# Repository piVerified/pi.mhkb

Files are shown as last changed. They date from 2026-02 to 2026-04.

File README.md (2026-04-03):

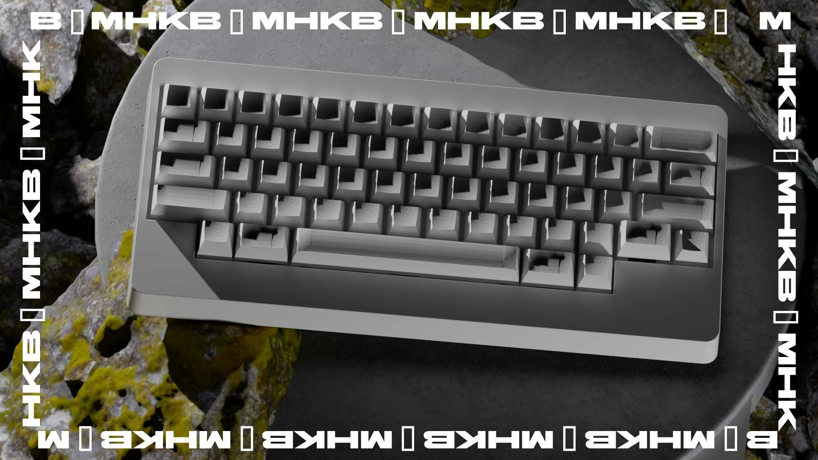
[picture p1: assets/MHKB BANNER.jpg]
BANNER


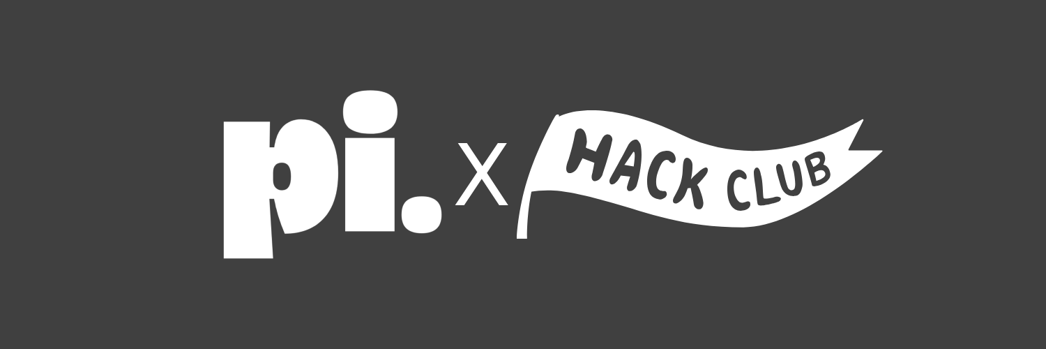
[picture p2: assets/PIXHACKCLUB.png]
COLLAB

# pi.mhkb

Introducing pi.mhkb, a completely custom made HHKB style mechanical keyboard

---
# Features

1. Full HHKB layout with custom key mapping
2. Custom PCB designed in KiCAD
3. 3D printed case designed in Fusion 360

## Fusion 360

### 1. Case

| Top | Side |
| :-: | :--: |
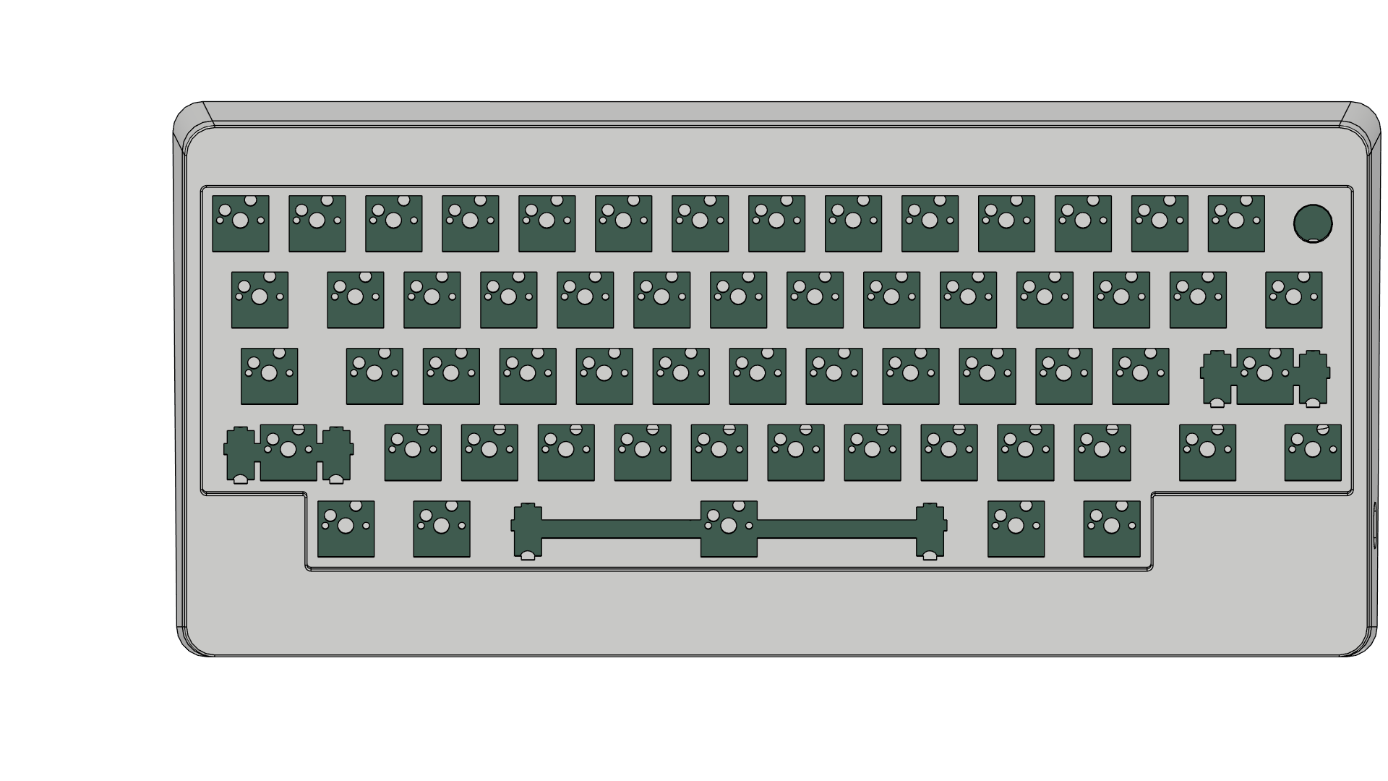
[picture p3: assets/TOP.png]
TOP
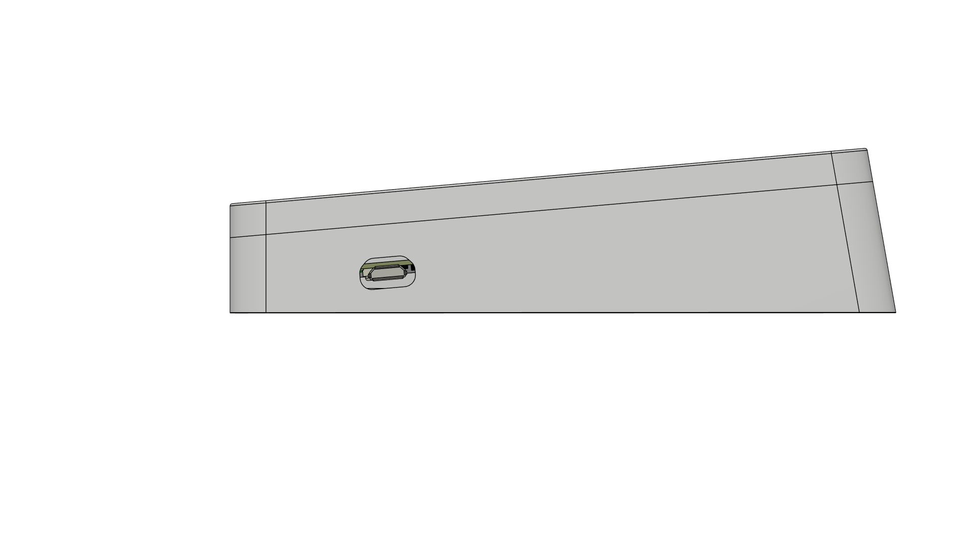
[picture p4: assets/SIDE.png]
SIDE
|  | |

---
## KiCAD

| Schematic |
| :-------: |
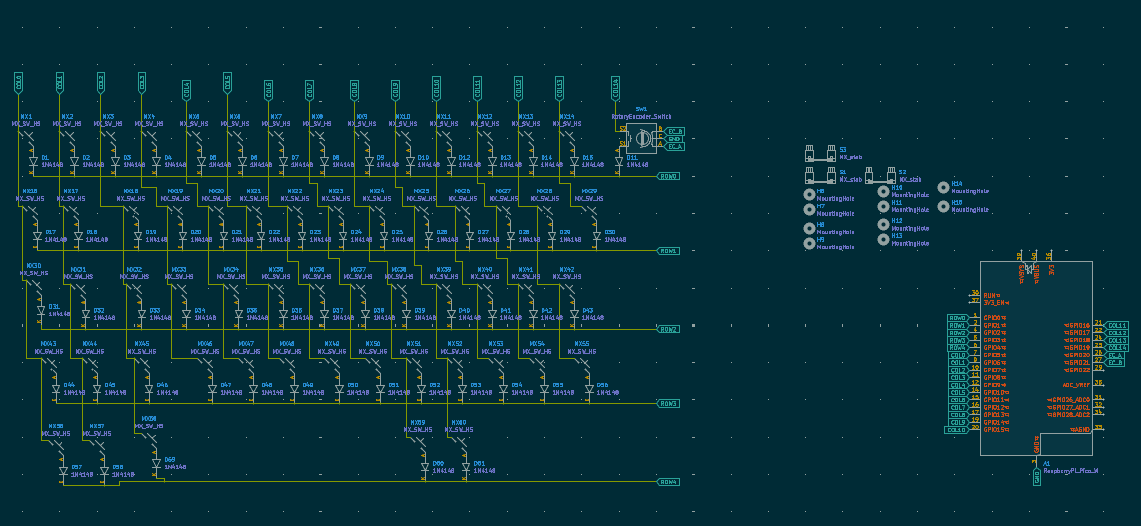
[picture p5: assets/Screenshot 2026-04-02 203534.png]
SCHEMATIC
||
| PCB |
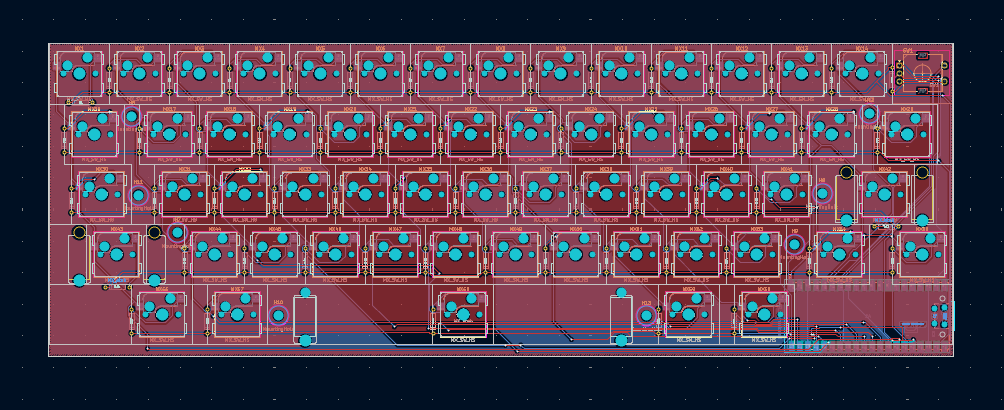
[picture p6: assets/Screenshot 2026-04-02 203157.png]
PCB
|  |

---
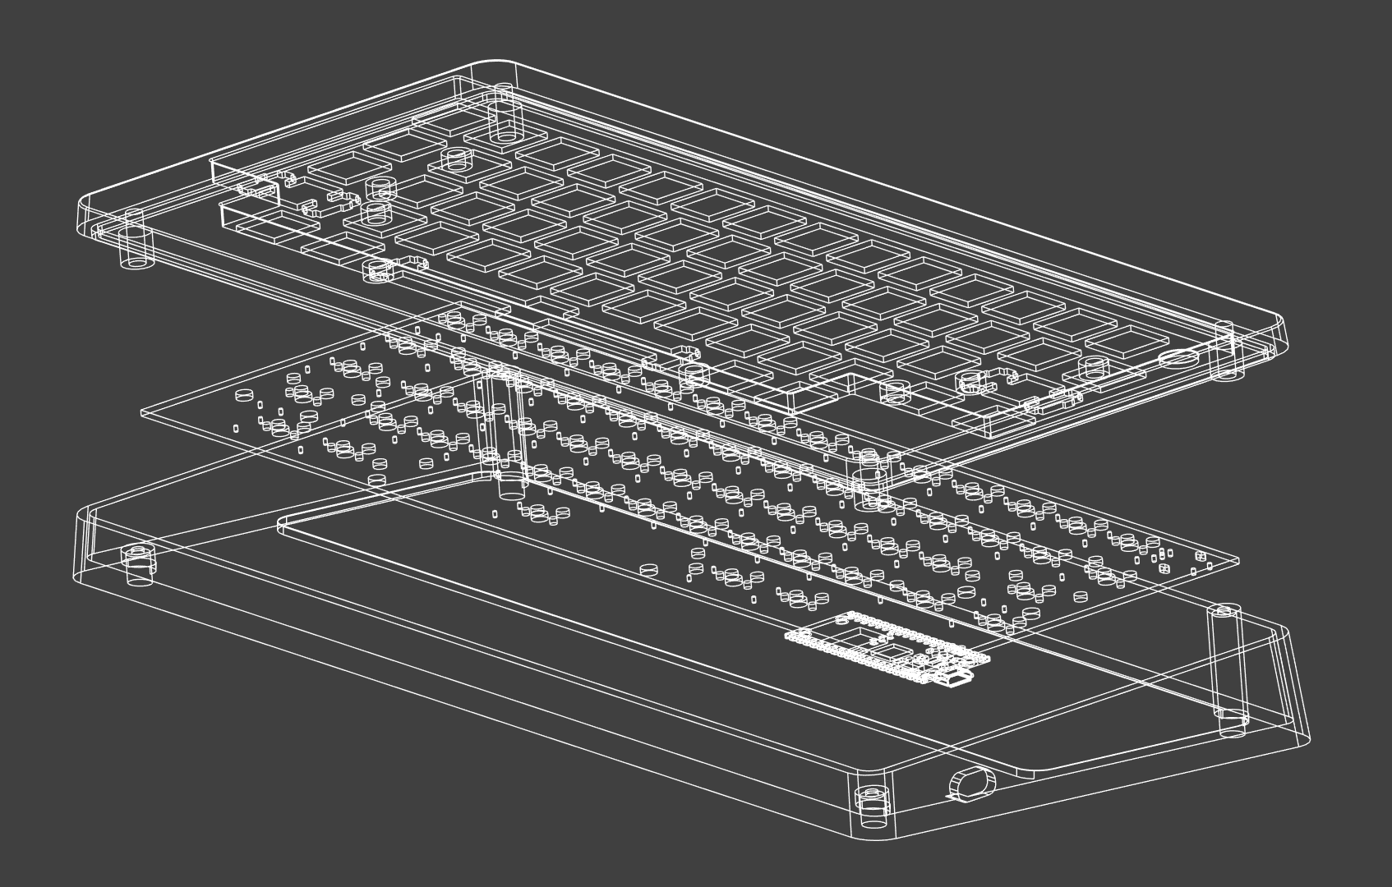
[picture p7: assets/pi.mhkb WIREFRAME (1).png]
WIREFRAME

#BOM
| Name | Purpose | Quantity | Total Cost (USD) | Distributor |
| :--- | :--- | ---: | ---: | :--- |
| PCB | the Brain | 1 | 37.94 | Robu |
| keycaps | covering the keys | 1 | 14.02 | curiosity caps |
| usb cable | for connecting and debugging | 1 | 1.72 | Amazon |
| keyboard Case | Enclousere of the system | 1 | 5.00 | #printinglegion |
| knob | for rotatory knob | 1 | 3.86 | Curiosity Caps |
| Stabilizers (set) | for the biggerkeys stability | 1 | 9.37 | KEEBSMOD |
| Gateron milky yellow | typing | 7 | 14.00 | Meckeys |
| Hotswap Sockets (set of 10) | to make it hotswapable | 7 | 5.81 | Mecheys |
| M3x4 mm Brass Heat Set Threaded Round Insert Nut (x25) | for housing screws | 1 | 0.98 | Robu |
| Raspberry Pi Pico WH | the main controller | 1 | 5.50 | Robu |
| 1N4148 1W Zener Diode | to prevent ghosting of keys | 70 | 0.70 | Robu |

---
# Softwares Used

* KiCAD -> PCB Design
* Fusion 360 -> Case design
* Blender -> Cover Image

---
# Bibliography

> This project would not have been possible without the help of the amazing people of the internet and the Hack Club community.

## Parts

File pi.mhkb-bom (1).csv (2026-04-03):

Name | Purpose | Quantity | Total Cost (USD) | Link | Distributor
screws | to assemble case and | 20 | 1.41 | https://onlyscrews.in/products/chhd-m3-x-6mm-pack-of-22?variant=48458858889529 | onlyscrews
PCB | the Brain | 1 | 37.94 | https://robu.in/cart/ | Robu
keycaps | covering the keys | 1 | 14.02 | https://curiositycaps.in/products/mecha-white-cherry-doubleshot-pbt-keycaps-bag-packaging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 | curiosity caps
usb cable | for connecting and debugging | 1 | 1.72 | https://www.amazon.in/Portronics-Konnect-POR-1079-Charging-Micro/dp/B08CDKQ8T6 | Amazon
keyboard Case | Enclousere of the system | 1 | 5.00 | https://hackclub.enterprise.slack.com/archives/C095YP8GLKT | #printinglegion
knob | for rotatory knob | 1 | 3.86 | https://curiositycaps.in/products/untitled-20oct_19-06?variant=49832025162009 | Curiosity Caps
Stabilizers (set) | for the biggerkeys stability | 1 | 9.37 | https://www.keebsmod.com/products/ws-stupid-stabilizer?variant=48977849745706 | KEEBSMOD
Gateron milky yellow | typing | 7 | 14.00 | https://meckeys.com/shop/accessories/keyboard-accessories/key-switches/gateron-mechanical-pro-switch-5pin/ | Meckeys
Hotswap Sockets (set of 10) | to make it hotswapable | 7 | 5.81 | https://meckeys.com/shop/accessories/keyboard-accessories/key-switches/kailh-hot-swap-socket/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 | Mecheys
M3x4 mm Brass Heat Set Threaded Round Insert Nut (x25) | for housing screws | 1 | 0.98 | https://robu.in/product/m3-x-4-mm-brass-heat-set-knurl-threaded-round-insert-nut-25-pcs/ | Robu
Raspberry Pi Pico WH | the main controller | 1 | 5.50 | https://robu.in/product/raspberry-pi-pico-with-headers/ | Robu
1N4148 1W Zener Diode | to prevent ghosting of keys | 70 | 0.70 | https://robu.in/product/1n4148-1w-zener-diode-pack-of-50/ | Robu

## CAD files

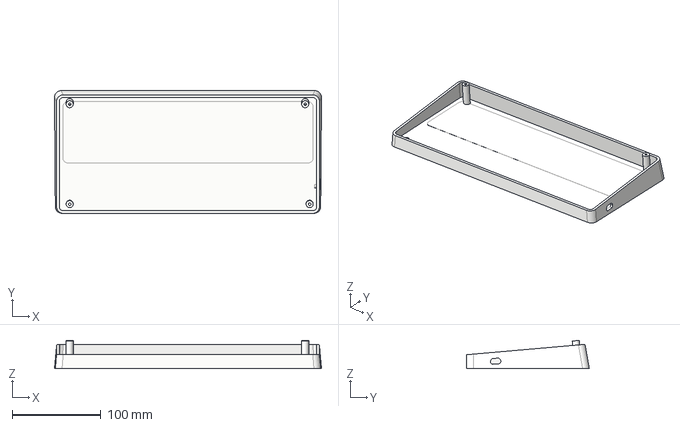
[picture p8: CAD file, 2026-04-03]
CAD/pi.mhkb(base).step
300.4 x 138.0 x 31.7 mm

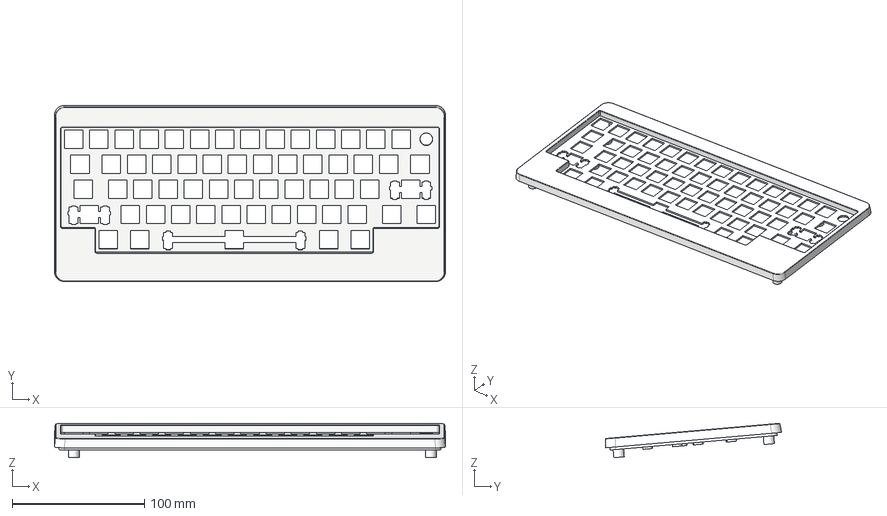
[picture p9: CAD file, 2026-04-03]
CAD/pi.mhkb(top) (2).step
295.8 x 133.2 x 26.0 mm

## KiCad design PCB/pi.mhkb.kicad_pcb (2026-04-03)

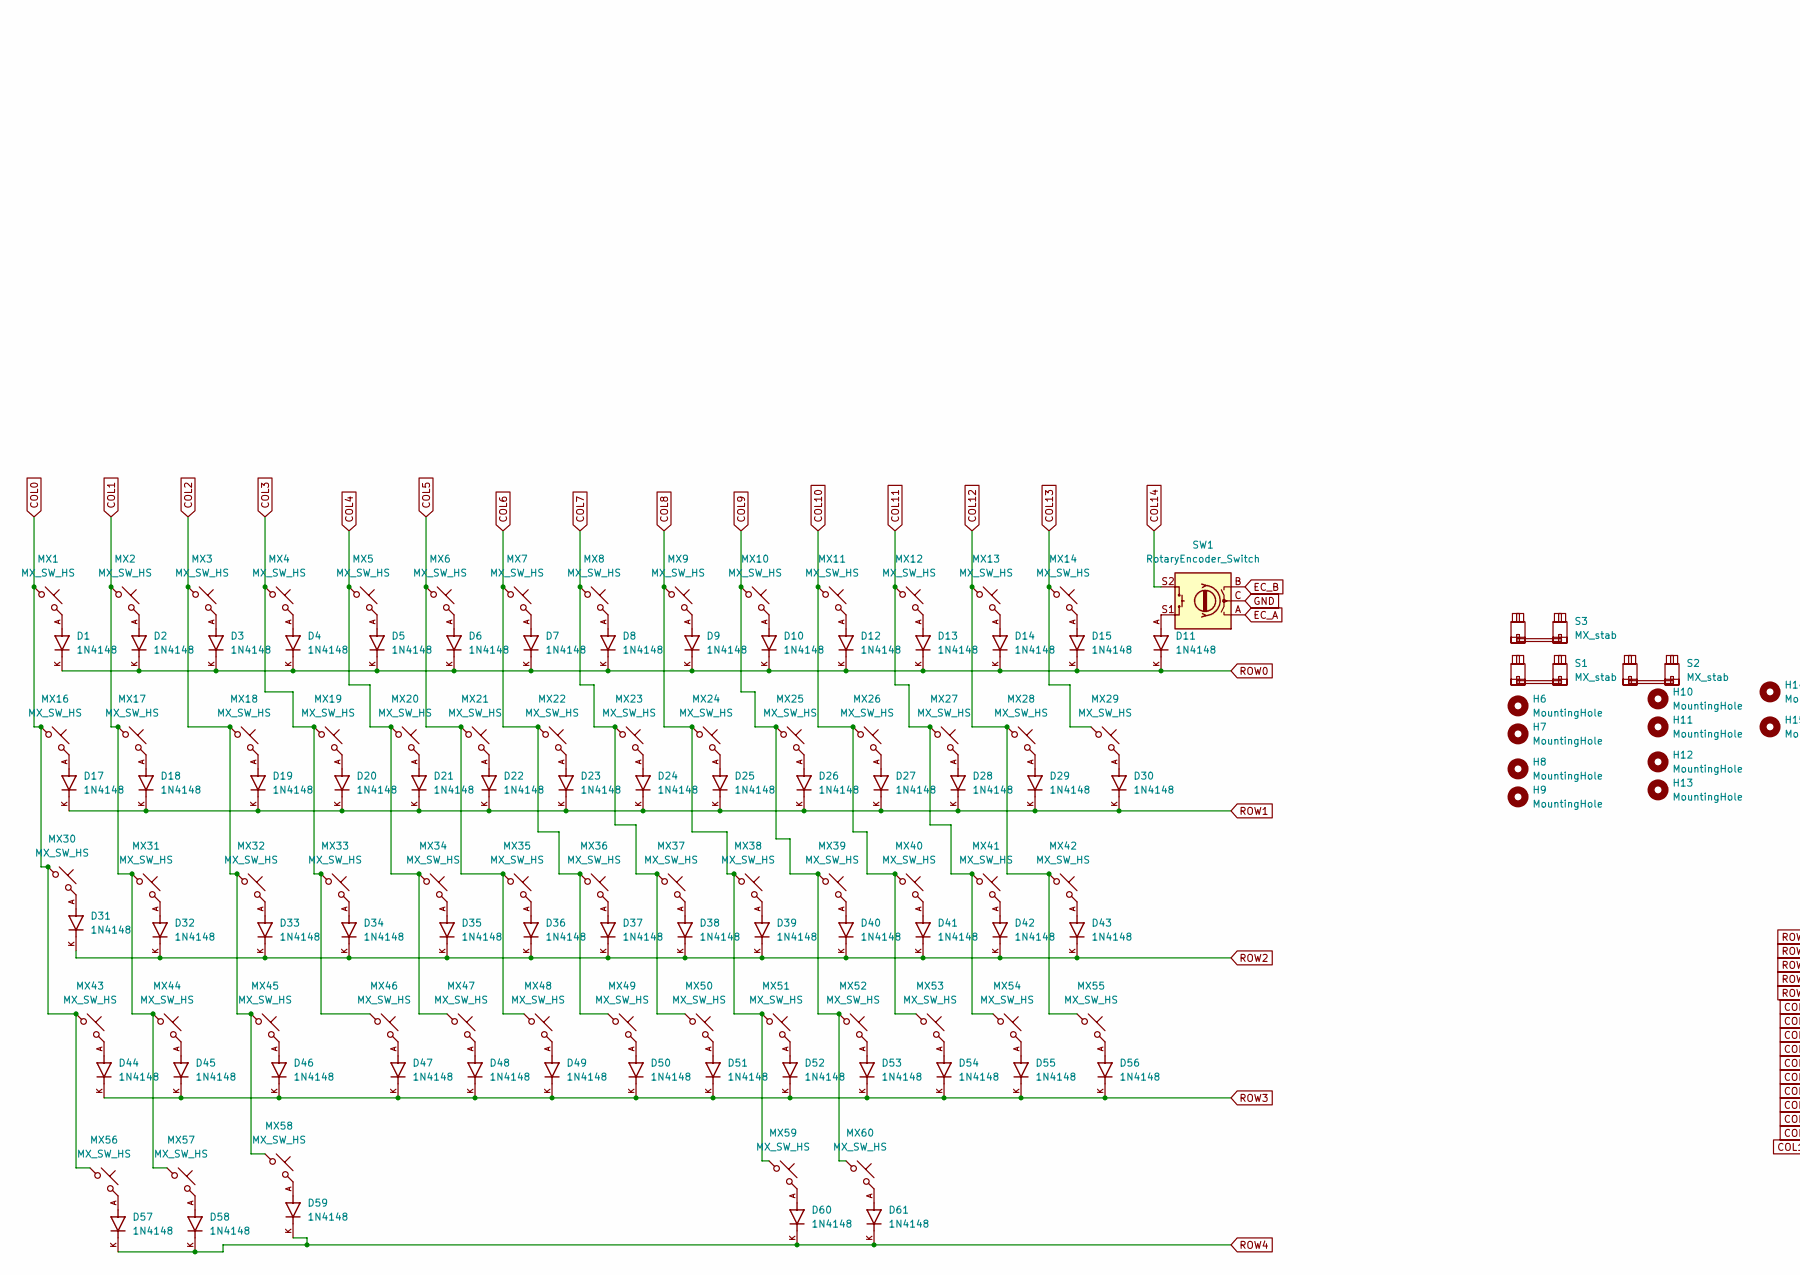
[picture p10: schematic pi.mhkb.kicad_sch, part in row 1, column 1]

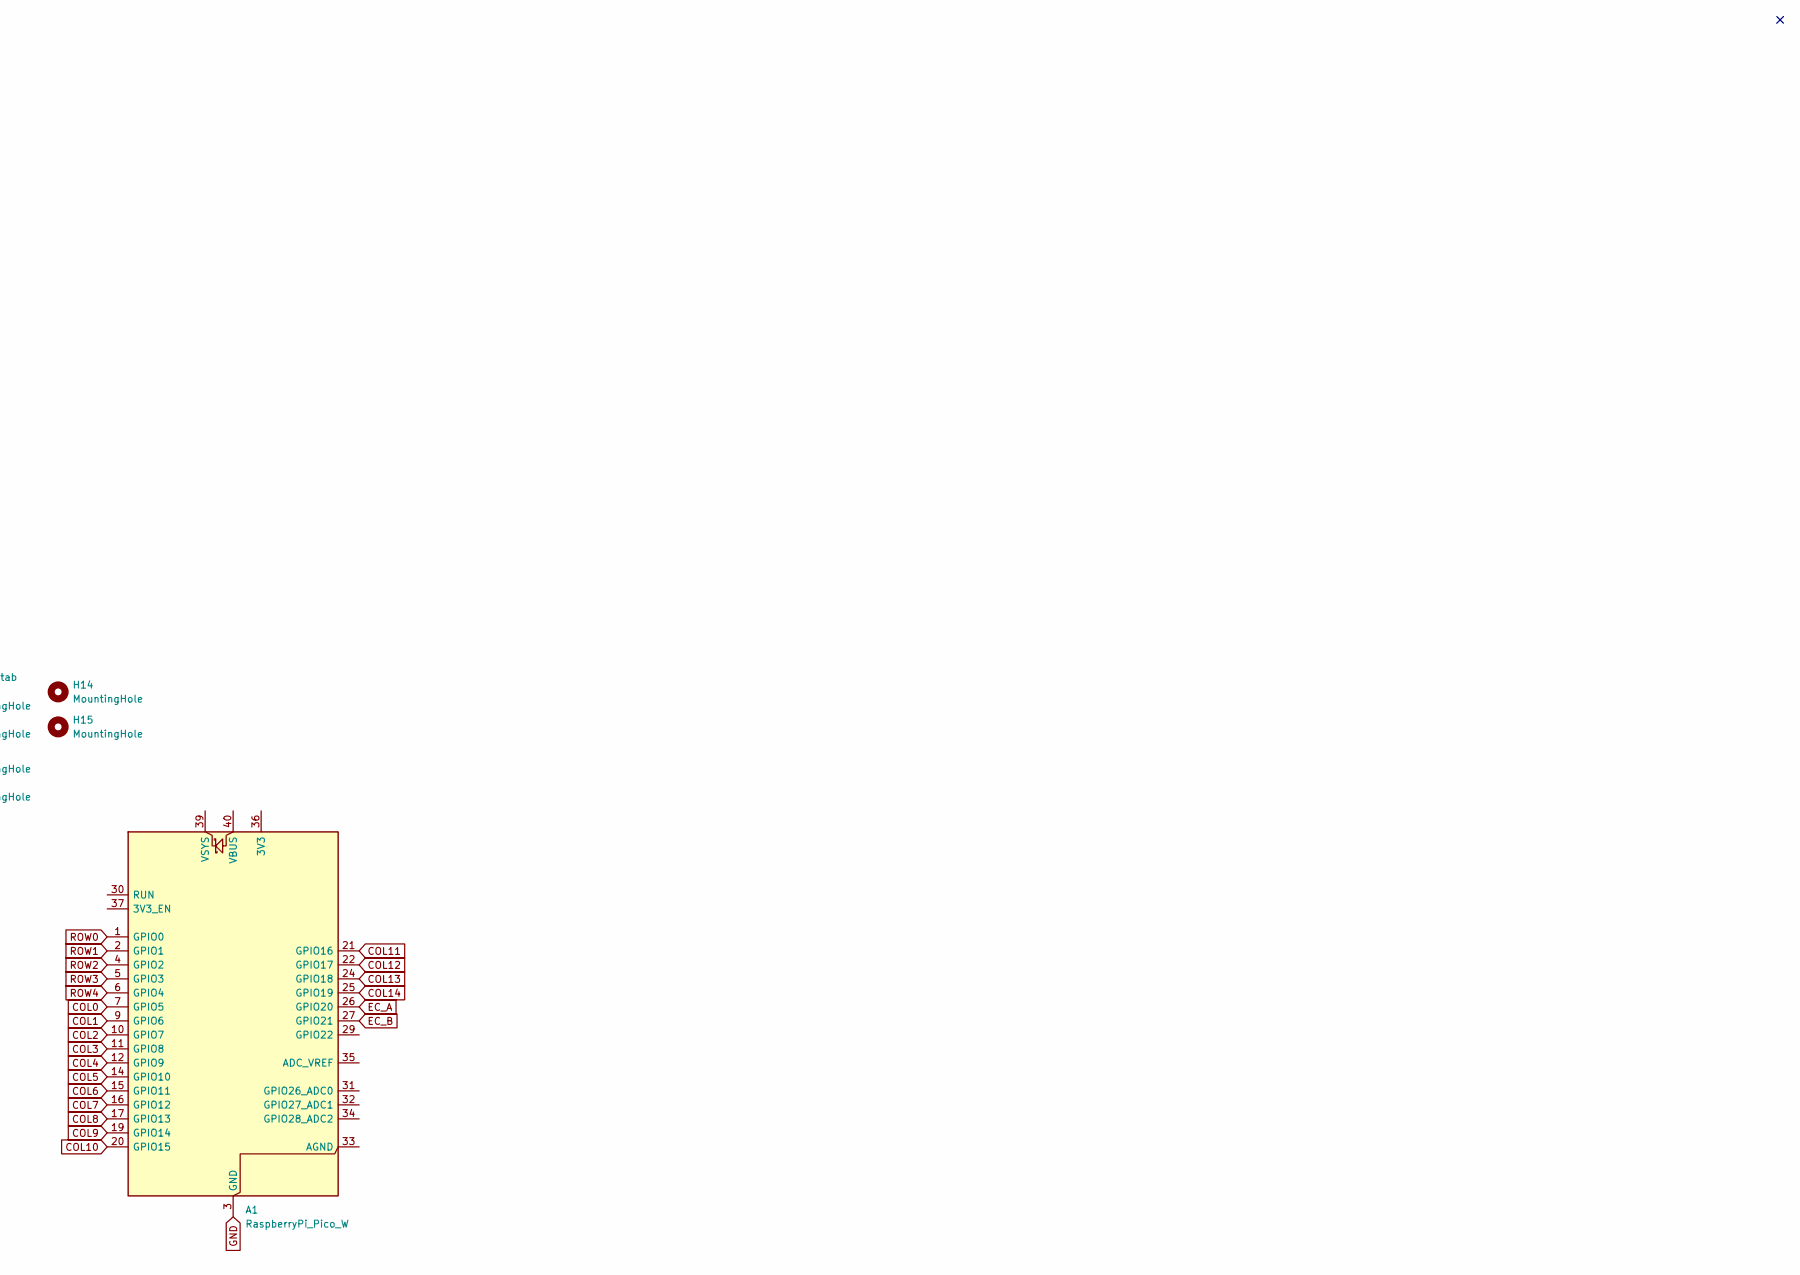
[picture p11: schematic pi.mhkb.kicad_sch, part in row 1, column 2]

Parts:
A1: RaspberryPi_Pico_W; RaspberryPi_Pico_W_SMD_HandSolder
D1, D2, D3, D4, D5, D6, D7, D8, D9, D10, D11, D12, D13, D14, D15, D17, D18, D19, D20, D21, D22, D23, D24, D25, D26, D27, D28, D29, D30, D31, D32, D33, D34, D35, D36, D37, D38, D39, D40, D41, D42, D43, D44, D45, D46, D47, D48, D49, D50, D51, D52, D53, D54, D55, D56, D57, D58, D59, D60, D61: 1N4148; DIODE-1N4148; PARTREV 5
H6, H7, H8, H9, H10, H11, H12, H13, H14, H15: MountingHole; MountingHole_3.2mm_M3
MX1, MX2, MX3, MX4, MX5, MX6, MX7, MX8, MX9, MX10, MX11, MX12, MX13, MX14, MX16, MX17, MX18, MX19, MX20, MX21, MX22, MX23, MX24, MX25, MX26, MX27, MX28, MX29, MX30, MX31, MX32, MX33, MX34, MX35, MX36, MX37, MX38, MX39, MX40, MX41, MX42, MX43, MX44, MX45, MX46, MX47, MX48, MX49, MX50, MX51, MX52, MX53, MX54, MX55, MX56, MX57, MX58, MX59, MX60: MX_SW_HS; SW_Hotswap_Kailh_MX_1.00u
S1, S2: MX_stab; STAB_MX_P_2.25u
S3: MX_stab; Stabilizer_Cherry_MX_6.25u
SW1: RotaryEncoder_Switch; RotaryEncoder_Alps_EC11E-Switch_Vertical_H20mm

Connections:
COL0: A1.7 (GPIO5), MX1.1, MX16.1, MX30.1, MX43.1, MX56.1
COL1: A1.9 (GPIO6), MX2.1, MX17.1, MX31.1, MX44.1, MX57.1
COL2: A1.10 (GPIO7), MX3.1, MX18.1, MX32.1, MX45.1, MX58.1
COL3: A1.11 (GPIO8), MX4.1, MX19.1, MX33.1, MX46.1
COL4: A1.12 (GPIO9), MX5.1, MX20.1, MX34.1, MX47.1
COL5: A1.14 (GPIO10), MX6.1, MX21.1, MX35.1, MX48.1
COL6: A1.15 (GPIO11), MX7.1, MX22.1, MX36.1, MX49.1
COL7: A1.16 (GPIO12), MX8.1, MX23.1, MX37.1, MX50.1
COL8: A1.17 (GPIO13), MX9.1, MX24.1, MX38.1, MX51.1, MX59.1
COL9: A1.19 (GPIO14), MX10.1, MX25.1, MX39.1, MX52.1, MX60.1
COL10: A1.20 (GPIO15), MX11.1, MX26.1, MX40.1, MX53.1
COL11: A1.21 (GPIO16), MX12.1, MX27.1, MX41.1, MX54.1
COL12: A1.22 (GPIO17), MX13.1, MX28.1, MX42.1, MX55.1
COL13: A1.24 (GPIO18), MX14.1, MX29.1
COL14: A1.25 (GPIO19), SW1.S2
EC_A: A1.26 (GPIO20), SW1.A
EC_B: A1.27 (GPIO21), SW1.B
GND: A1.3 (GND), A1.8 (GND), A1.13 (GND), A1.18 (GND), A1.23 (GND), A1.28 (GND), A1.38 (GND), SW1.C
unnamed: D1.A, MX1.2
unnamed: D2.A, MX2.2
unnamed: D3.A, MX3.2
unnamed: D4.A, MX4.2
unnamed: D5.A, MX5.2
unnamed: D6.A, MX6.2
unnamed: D7.A, MX7.2
unnamed: D8.A, MX8.2
unnamed: D9.A, MX9.2
unnamed: D10.A, MX10.2
unnamed: D11.A, SW1.S1
unnamed: D12.A, MX11.2
unnamed: D13.A, MX12.2
unnamed: D14.A, MX13.2
unnamed: D15.A, MX14.2
unnamed: D17.A, MX16.2
unnamed: D18.A, MX17.2
unnamed: D19.A, MX18.2
unnamed: D20.A, MX19.2
unnamed: D21.A, MX20.2
unnamed: D22.A, MX21.2
unnamed: D23.A, MX22.2
unnamed: D24.A, MX23.2
unnamed: D25.A, MX24.2
unnamed: D26.A, MX25.2
unnamed: D27.A, MX26.2
unnamed: D28.A, MX27.2
unnamed: D29.A, MX28.2
unnamed: D30.A, MX29.2
unnamed: D31.A, MX30.2
unnamed: D32.A, MX31.2
unnamed: D33.A, MX32.2
unnamed: D34.A, MX33.2
unnamed: D35.A, MX34.2
unnamed: D36.A, MX35.2
unnamed: D37.A, MX36.2
unnamed: D38.A, MX37.2
unnamed: D39.A, MX38.2
unnamed: D40.A, MX39.2
unnamed: D41.A, MX40.2
unnamed: D42.A, MX41.2
unnamed: D43.A, MX42.2
unnamed: D44.A, MX43.2
unnamed: D45.A, MX44.2
unnamed: D46.A, MX45.2
unnamed: D47.A, MX46.2
unnamed: D48.A, MX47.2
unnamed: D49.A, MX48.2
unnamed: D50.A, MX49.2
unnamed: D51.A, MX50.2
unnamed: D52.A, MX51.2
unnamed: D53.A, MX52.2
unnamed: D54.A, MX53.2
unnamed: D55.A, MX54.2
unnamed: D56.A, MX55.2
unnamed: D57.A, MX56.2
unnamed: D58.A, MX57.2
unnamed: D59.A, MX58.2
unnamed: D60.A, MX59.2
unnamed: D61.A, MX60.2
ROW0: A1.1 (GPIO0), D1.K, D2.K, D3.K, D4.K, D5.K, D6.K, D7.K, D8.K, D9.K, D10.K, D11.K, D12.K, D13.K, D14.K, D15.K
ROW1: A1.2 (GPIO1), D17.K, D18.K, D19.K, D20.K, D21.K, D22.K, D23.K, D24.K, D25.K, D26.K, D27.K, D28.K, D29.K, D30.K
ROW2: A1.4 (GPIO2), D31.K, D32.K, D33.K, D34.K, D35.K, D36.K, D37.K, D38.K, D39.K, D40.K, D41.K, D42.K, D43.K
ROW3: A1.5 (GPIO3), D44.K, D45.K, D46.K, D47.K, D48.K, D49.K, D50.K, D51.K, D52.K, D53.K, D54.K, D55.K, D56.K
ROW4: A1.6 (GPIO4), D57.K, D58.K, D59.K, D60.K, D61.K

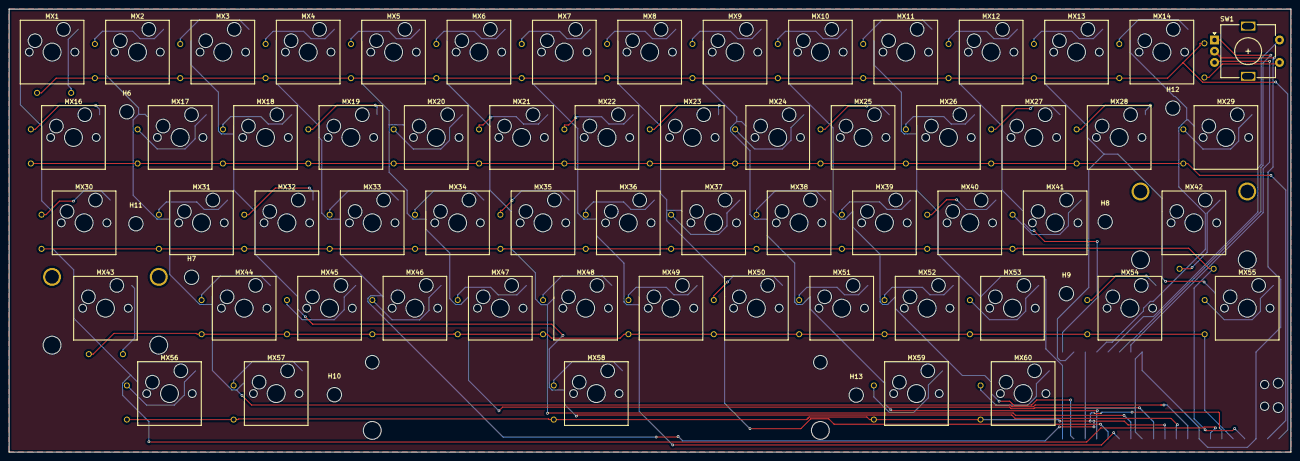
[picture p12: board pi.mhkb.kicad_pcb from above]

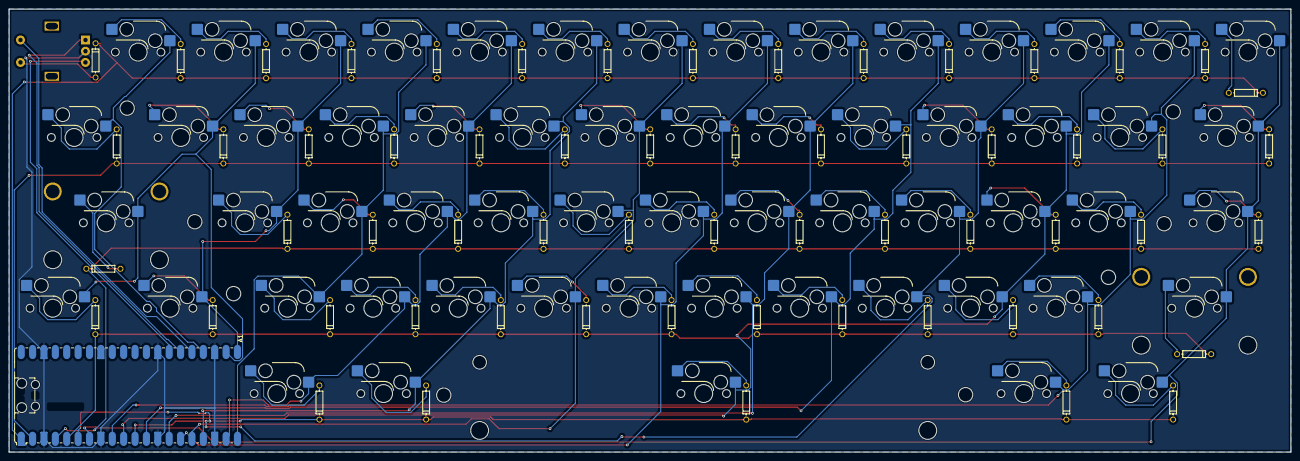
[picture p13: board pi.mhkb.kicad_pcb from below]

Board: 2 copper layers, 286.1 x 98.9 mm, 132 parts (61 on the bottom side), 83 nets.

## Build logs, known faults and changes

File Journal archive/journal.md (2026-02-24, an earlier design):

# Journal

You can find the original Journal at [Scrap Book](https://scrapbook.hackclub.com/pi.obj)

---

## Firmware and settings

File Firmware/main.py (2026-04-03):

import board
from kmk.kmk_keyboard import KMKKeyboard
from kmk.keys import KC
from kmk.scanners import DiodeOrientation
from kmk.extensions.encoder import Encoder

keyboard = KMKKeyboard()

# 1. Matrix Configuration
# Rows: GP0 to GP4
# Cols: GP5 to GP15, GP18 to GP21
keyboard.row_pins = (board.GP0, board.GP1, board.GP2, board.GP3, board.GP4)
keyboard.col_pins = (
    board.GP5, board.GP6, board.GP7, board.GP8, board.GP9, 
    board.GP10, board.GP11, board.GP12, board.GP13, board.GP14, 
    board.GP15, board.GP18, board.GP19, board.GP20, board.GP21
)

# Based on 1N4148 diodes pointing from Row to Column
keyboard.diode_orientation = DiodeOrientation.ROW2COL

# 2. Rotary Encoder Configuration
# Based on the schematic: EC_A -> GP27, EC_B -> GP26, SW -> GP22
encoder = Encoder()
keyboard.extensions.append(encoder)

encoder.pins = (
    (board.GP27, board.GP26, board.GP22, False), # (A, B, Tap, inverted)
)

# Encoder behavior: Volume Up/Down and Mute on tap
encoder.map = [
    ((KC.VOLU, KC.VOLD, KC.MUTE),), # Layer 0
]

# 3. Keymap
# This follows the 60% HHKB-ish layout from your previous image
# 'None' or 'KC.NO' is used for the gaps/blockers
keyboard.keymap = [
    [
        KC.ESC,  KC.N1,   KC.N2,   KC.N3,   KC.N4,   KC.N5,   KC.N6,   KC.N7,   KC.N8,   KC.N9,   KC.N0,   KC.MINS, KC.EQL,  KC.BSLS, KC.NO,
        KC.TAB,  KC.Q,    KC.W,    KC.E,    KC.R,    KC.T,    KC.Y,    KC.U,    KC.I,    KC.O,    KC.P,    KC.LBRC, KC.RBRC, KC.DEL,  KC.NO,
        KC.LCTL, KC.A,    KC.S,    KC.D,    KC.F,    KC.G,    KC.H,    KC.J,    KC.K,    KC.L,    KC.SCLN, KC.QUOT, KC.ENT,  KC.NO,   KC.NO,
        KC.LSFT, KC.Z,    KC.X,    KC.C,    KC.V,    KC.B,    KC.N,    KC.M,    KC.COMM, KC.DOT,  KC.SLSH, KC.RSFT, KC.MO(1), KC.NO,   KC.NO,
        KC.NO,   KC.LOPT, KC.LGUI, KC.NO,   KC.NO,   KC.SPC,  KC.NO,   KC.NO,   KC.RGUI, KC.ROPT, KC.NO,   KC.NO,   KC.NO,   KC.NO,   KC.NO,
    ]
]

if __name__ == '__main__':
    keyboard.go()

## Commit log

2026-02-24 Update README: Modify features and software used
    Removed BOM section and added Blender to software list.
2026-04-03 Update README with images for case and KiCAD
    Added images to README for keyboard case, schematic, and PCB.
2026-04-03 Add BOM section and wireframe image to README
